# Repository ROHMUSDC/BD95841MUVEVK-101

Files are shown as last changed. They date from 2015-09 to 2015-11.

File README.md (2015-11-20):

# BD95841MUVEVK-101 Design Resource Repository
* Hardware Design Files and Documentation for the ROHM BD95841MUVEVK-101 EVK

----
### Description: 
* BD95841MUV is a 1ch synchronous buck converter that can generate output voltages between 0.8V to 5.5V at an input voltage range of 7.5V to 15V. 
* Built-in N-MOSFET power transistors help to achieve small solution footprint and high efficiency
* Incorporates ROHM's H3Reg(TM) technology, a Rohm proprietary constant ON TIME control mode which facilitates ultra-high transient response against changes in load without external compensation components. 
* Includes fixed soft start function, power good function, and short circuit/over voltage protection with timer latch functions

----
### Repository Contents
* Application Note Folder: Contains Draft Version of EVK Application Note
* Design Files: Contains Board, Gerber, Schematic, and BOM information for this EVK Board
* Measurement Reports Folder: Contains measurement testing information completed for these EVK Boards

----
### Where to Purchase?
* http://www.rohm.com/web/global/distribution/-/dinventory/BD95841MUV-E2/sample/0

----
### DISCLAIMER
This Technical Data is protected under copyright laws.

ROHM hereby grants you a nonexclusive, nontransferable license to use this Technical Data 
as long as you abide by the terms and conditions of this DISCLAIMER. 

However, you are not authorized to sell, loan, rent, lease, redistribute or license this Technical Data, 
in whole or in part, or in modified form, to anyone.

You may modify this Technical Data to suit your specific applications, 
but the rights to derivative works and said modifications shall belong to ROHM. 

You may make copies of this Technical Data as necessary for internal use only within your company.

In any case, the latest datasheet is considered the final design guideline and represents 
the only actual performance specifications.

ROHM shall not be responsible for ensuring proper application on all computer systems.
This Technical Data is provided AS IS. ROHM makes no guarantees, either implicitly or explicitly, 
regarding its usability, functionality, accuracy, merchantability, or fitness for a specific purpose.

In addition, you shall take full responsibility for the use of any information acquired from this Technical Data. 

ROHM does not assume warranty of any kind arising from the use of this Technical Data. ACCORDINGLY, 
IN NO EVENT SHALL ROHM BE RESPONSIBLE, WHETHER THROUGH CONTRACT OR TORT LIABILITY, 
FOR ANY DAMAGES (INCLUDING BUT NOT LIMITED TO LOST PROFITS OR OTHER INCIDENTAL, CONSEQUENTAL, 
OR PUNITIVE DAMAGES) ARISING OUT OF OR IN CONNECTION WITH THE USE OR APPLICATION OF THIS Technical Data.

Furthermore, this Technical Data is subject to change without notice.

Unless otherwise expressly provided herein, ROHM does not convey any license under patent rights 
or any other intellectual property rights (including those of third parties).

ROHM is not obligated to provide maintenance or support for the Technical Data.

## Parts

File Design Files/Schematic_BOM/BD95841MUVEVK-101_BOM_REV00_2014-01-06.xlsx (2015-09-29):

ROHM - TITLE & REVISION HISTORY Revised: Monday, January 06, 2014
xxxx Revision: 00
Bill Of Materials January 6,2014 11:04:57 | Page1
Item | Quantity | Reference | Part | PCB Footprint | DESCRIPTION | MANUFACTURER1 | MANUFACTURER1_PART# | DISTR1 | DISTR1_PART# | DNP
______________________________________________
1 | 1 | CR1 | SML-310MTT86 | LED_0603 | LED 570NM GREEN WTR CLR 0603 SMD | Rohm | SML-310MTT86 | DIGIKEY | 511-1299-1-ND
2 | 2 | C1,C2 | 10uF | C1206 | CAP CER 10UF 25V 20% X5R 1206 | Murata | GRM31CR61E106MA12L | DIGIKEY | 490-5423-1-ND
3 | 1 | C3 | 10000pF | C0603 | CAP CER 10000PF 50V 10% X7R 0603 | Murata | GRM188R71H103KA01D | DIGIKEY | 490-1512-2-ND
4 | 2 | C4,C5 | 22uF | C1206 | CAP CER 22UF 16V 10% X5R 1206 | Murata | GRM31CR61C226KE15K | DIGIKEY | 490-6512-1-ND
5 | 1 | C6 | 0.022uF | C0603 | CAP CER 0.022UF 50V 10% X7R 0603 | Murata | GRM188R71H223KA01D | DIGIKEY | 490-1517-2-ND
6 | 1 | C7 |  | C1206 |  |  |  |  |  | DNP( Do not place )
7 | 1 | C8 |  | C0805 |  |  |  |  |  | DNP( Do not place )
8 | 1 | C9 | 0.1uF | C0603 | CAP CER 0.1UF 25V 10% X7R 0603 | Murata | GRM188R71E104KA01D | DIGIKEY | 490-1524-2-ND
9 | 1 | D1 | SMAJ12A | DO-214AC | TVS DIODE 12VWM 19.9VC SMA | Littelfuse Inc | SMAJ12A | DIGIKEY | SMAJ12ALFTR-ND
10 | 2 | D2,D3 | RB085B-30TL | CPD | DIODE SCHOTTKY 30V 10A CPD | Rohm | RB085B-30TL | DIGIKEY | RB085B-30TLCT-ND | DNP( Do not place )
11 | 1 | J1 | 87224-3 | HDR_THVT_1X3_100 | CONN HEADER VERT .100 3POS 15AU | TE Connectivity Div | 87224-3 | DIGIKEY | A26545-ND
12 | 1 | L1 | 3.3uH | SMT_7P1X6P5 | INDUCTOR 3.3UH 6.8A 20% SMD | TDK Corporation | SPM6530T-3R3M | DIGIKEY | 445-4119-2-ND
13 | 1 | Q1 | SST2222AT116 | SOT23_BEC | TRANSISTOR NPN 40V 0.6A SOT-23 | Rohm | SST2222AT116 | DIGIKEY | SST2222AT116TR-ND
14 | 1 | R2 | 1.5K | R0603 | RES 1.5K OHM 1/10W 1% 0603 SMD | Rohm | RHM1.5KBJTR-ND | DIGIKEY | TRR03EZPF1501
15 | 1 | R3 | 13K | R0603 | RES 13K OHM 1/10W 1% 0603 SMD | Rohm | MCR03ERTF1302 | DIGIKEY | RHM13KCFTR-ND
16 | 1 | R4 | 4.7K | R0603 | RES 4.7K OHM 1/10W 1% 0603 SMD | Rohm | MCR03ERTF4701 | DIFIKEY | RHM4.70KCFTR-ND
17 | 1 | R5 | 100K | R0603 | RES 100K OHM 1/10W 5% 0603 SMD | Rohm | MCR03ERTJ104 | DIGIKEY | RHM100KCGTR-ND
18 | 1 | R6 | 1K | R0603 | RES 1K OHM 1/10W 5% 0603 SMD | Rohm | MCR03ERTJ102 | DIGIKEY | RHM1.0KCGTR-ND
19 | 1 | R7 | 30 | R0603 | RES 30 OHM 1/10W 5% 0603 SMD | Rohm | ESR03EZPJ300 | DIGIKEY | RHM30DTR-ND
20 | 3 | TP1,TP2,TP5 | TP_63Mil_TH | TP_TH | TEST POINT PC MULTI PURPOSE RED | Keystone Electronics | 5010 | DIGIKEY | 5010K-ND
21 | 2 | TP3,TP4 | TP_63Mil_TH | TP_TH | TEST POINT PC MULTI PURPOSE BLK | Keystone Electronics | 5011 | DIGIKEY | 5011K-ND
22 | 1 | U1 | BD95841MUV | VQFN016V3030 | 7.5V to 15V, 4A 1ch Synchronous Buck Converter | ROHM | BD95841MUV
23 | 1 | ZX1 | 0 | SM_180x060 | 1806 footprint solder-short during assembly
24 | 1 |  |  |  | Shunt jumper for header J1 (item #11), CONN SHUNT 2POS GOLD W/HANDLE | TE Connectivity | 881545-1 | DIGIKEY | 881545-1-ND

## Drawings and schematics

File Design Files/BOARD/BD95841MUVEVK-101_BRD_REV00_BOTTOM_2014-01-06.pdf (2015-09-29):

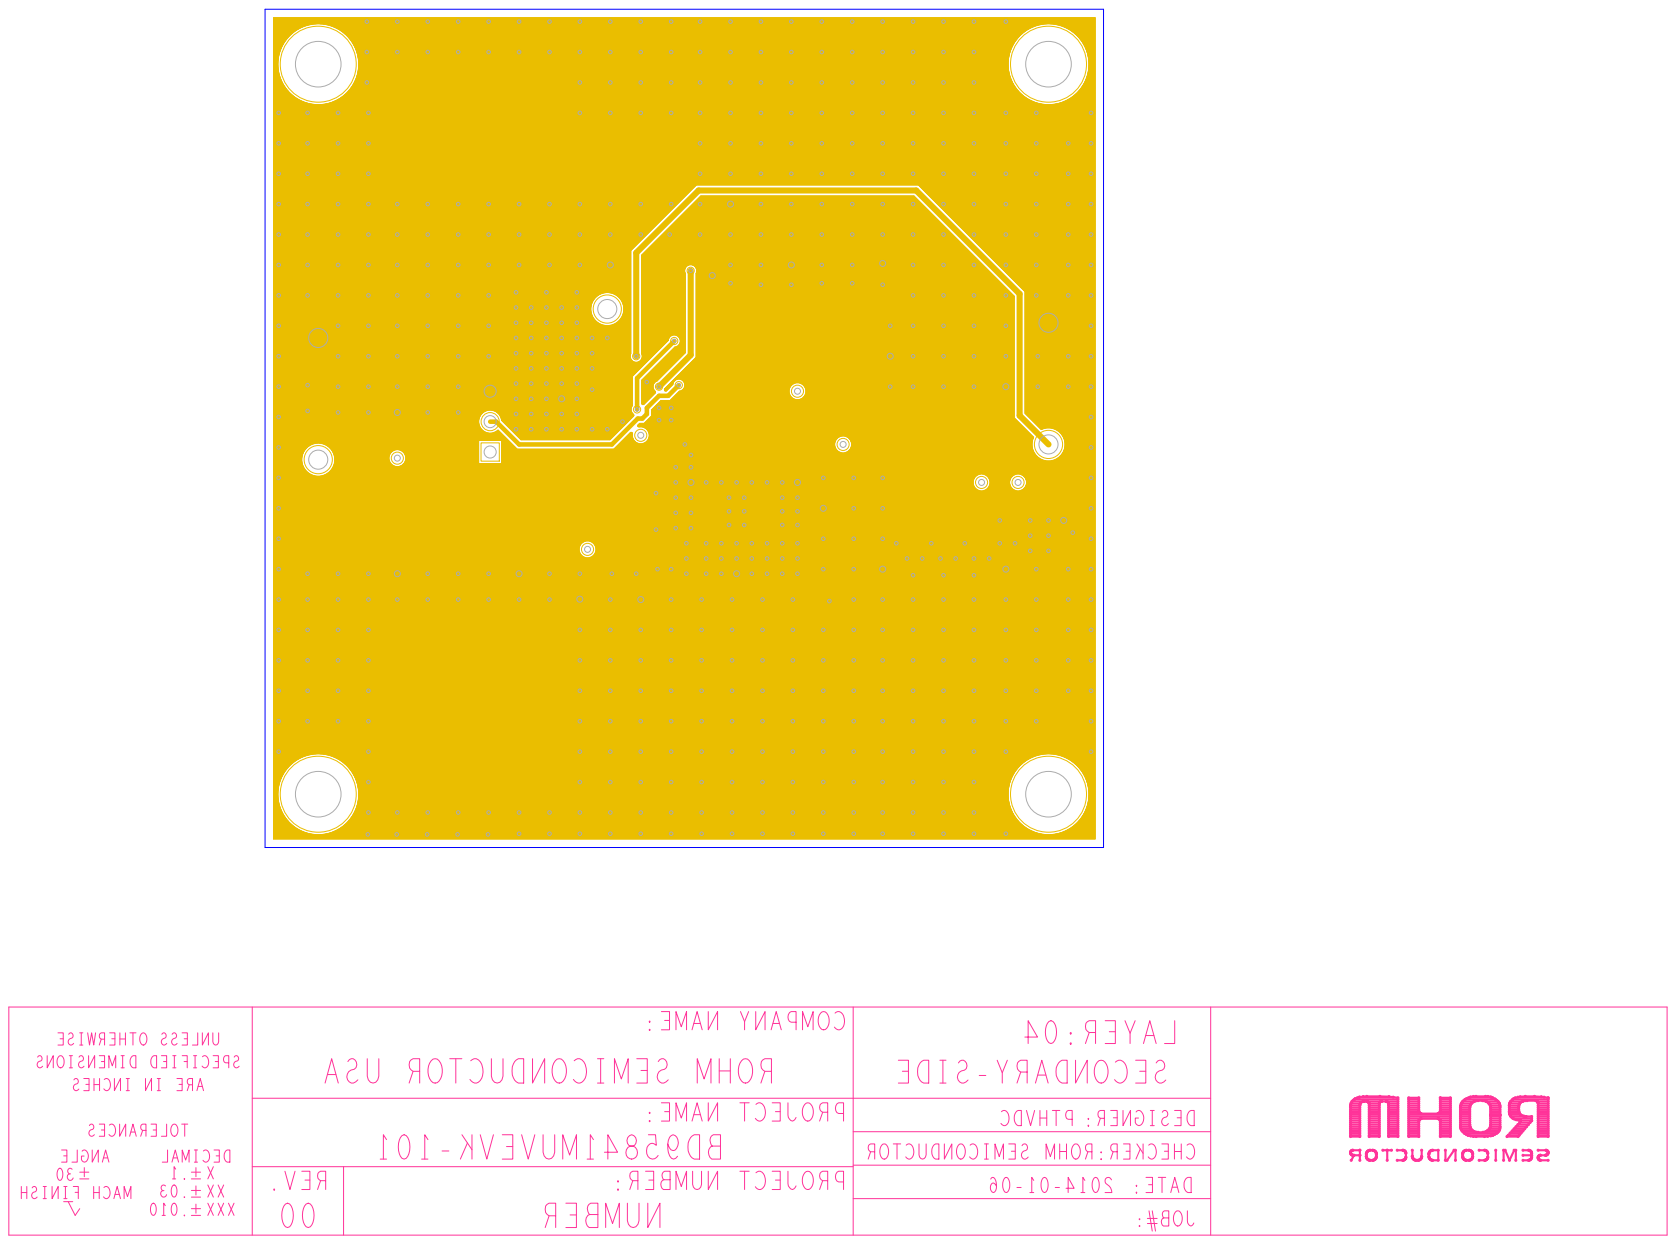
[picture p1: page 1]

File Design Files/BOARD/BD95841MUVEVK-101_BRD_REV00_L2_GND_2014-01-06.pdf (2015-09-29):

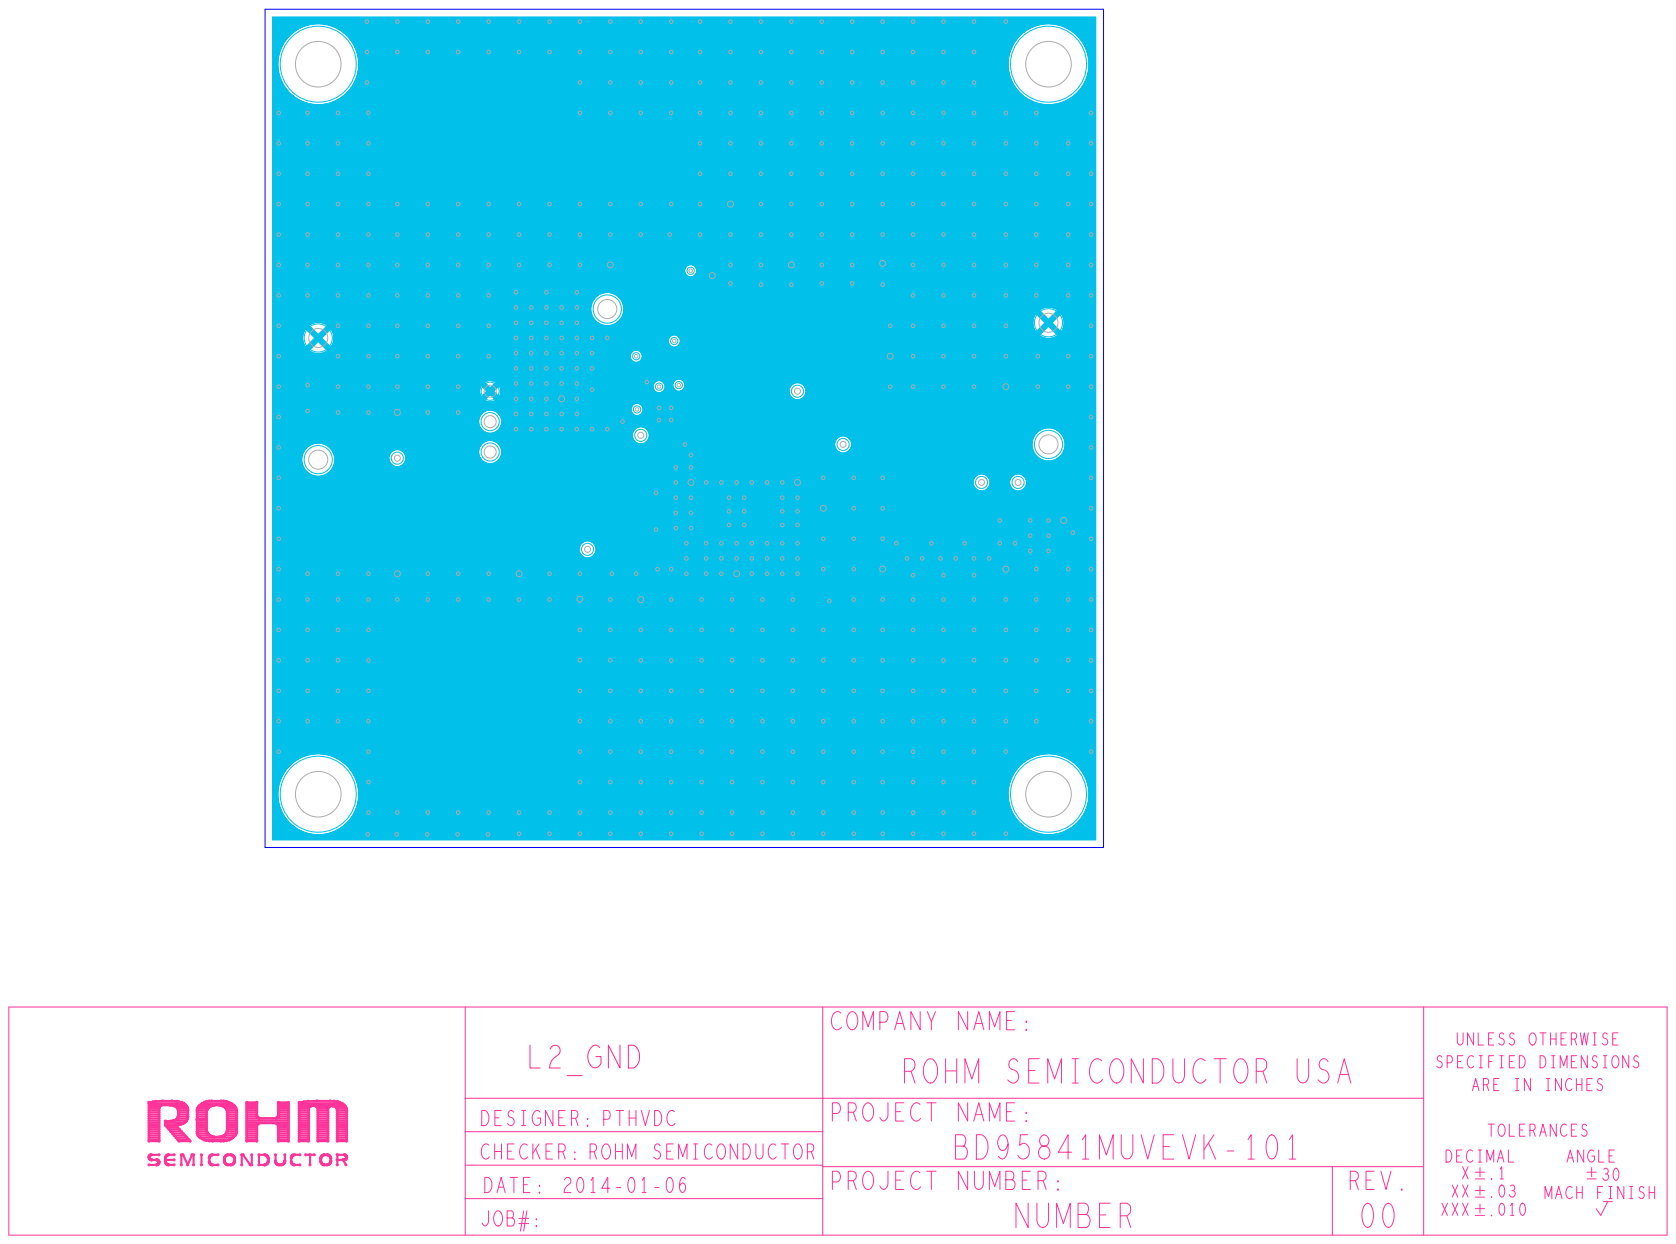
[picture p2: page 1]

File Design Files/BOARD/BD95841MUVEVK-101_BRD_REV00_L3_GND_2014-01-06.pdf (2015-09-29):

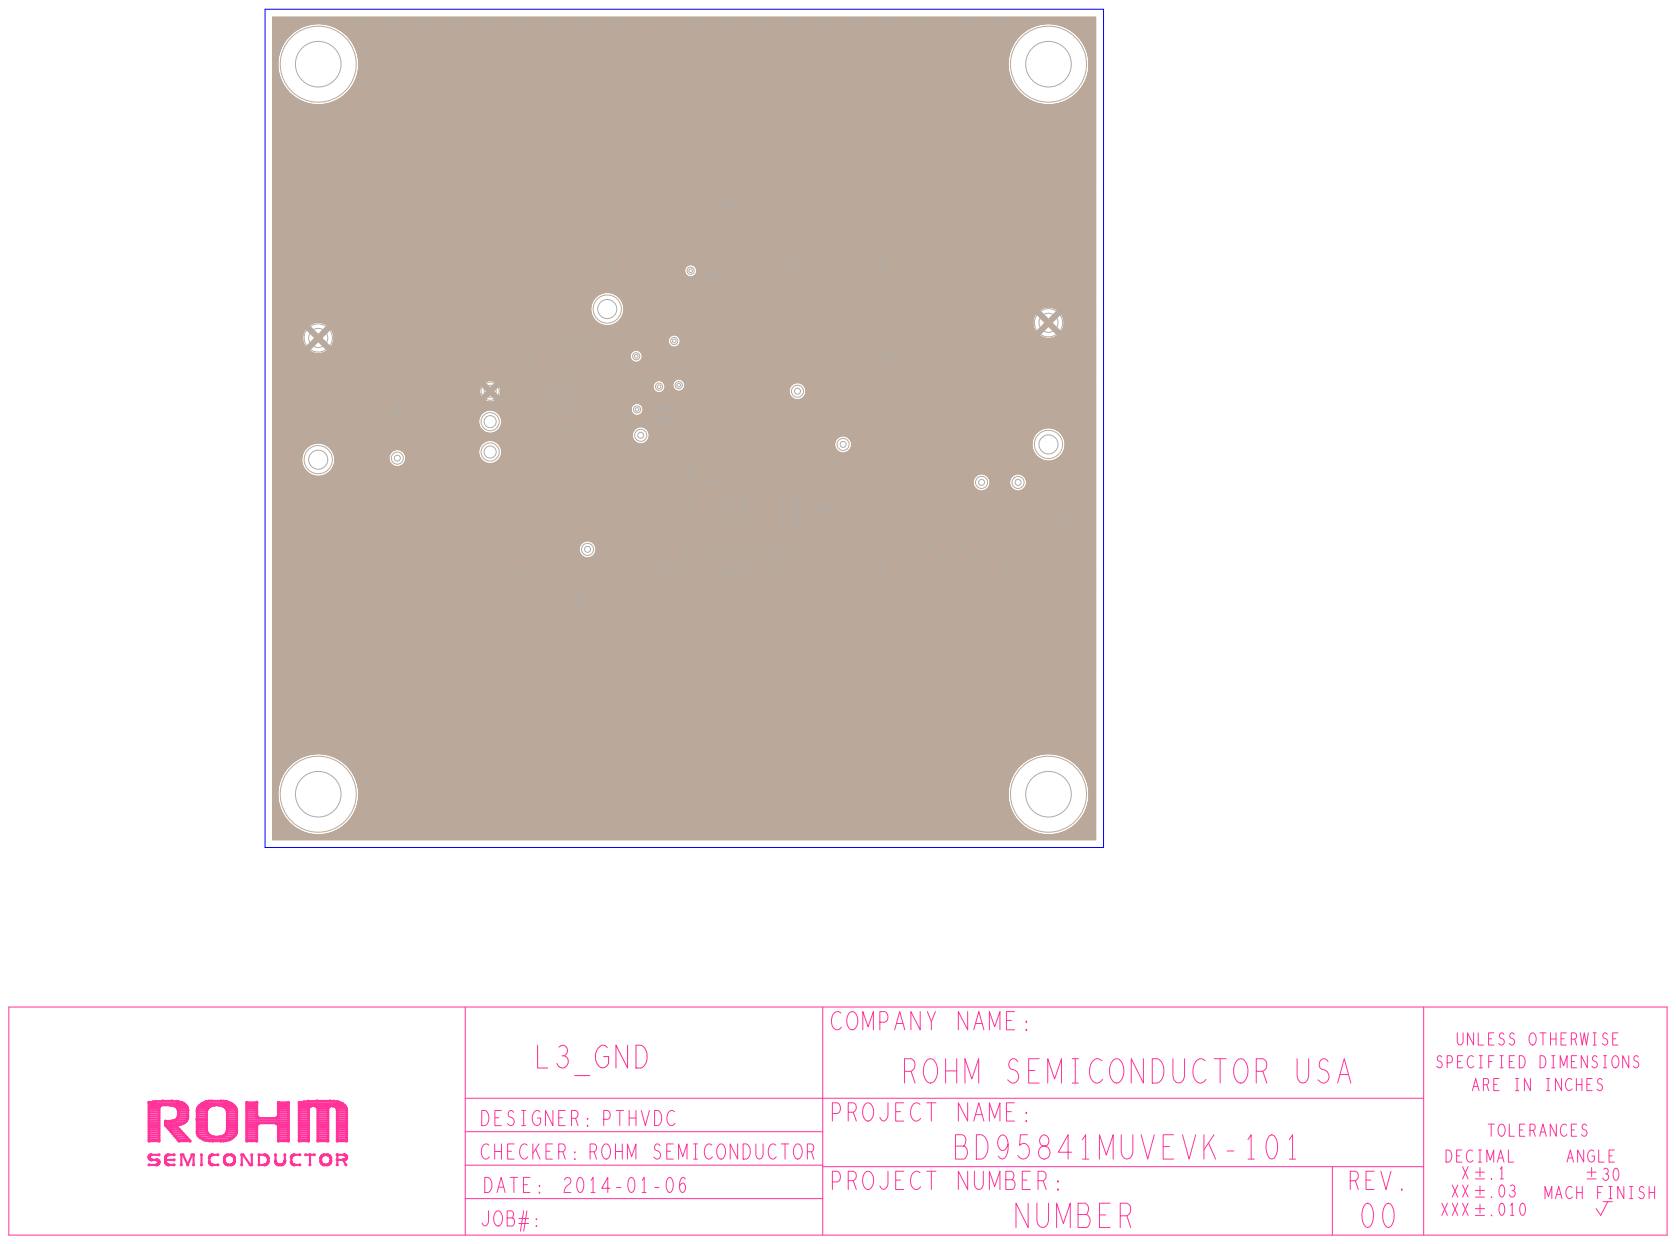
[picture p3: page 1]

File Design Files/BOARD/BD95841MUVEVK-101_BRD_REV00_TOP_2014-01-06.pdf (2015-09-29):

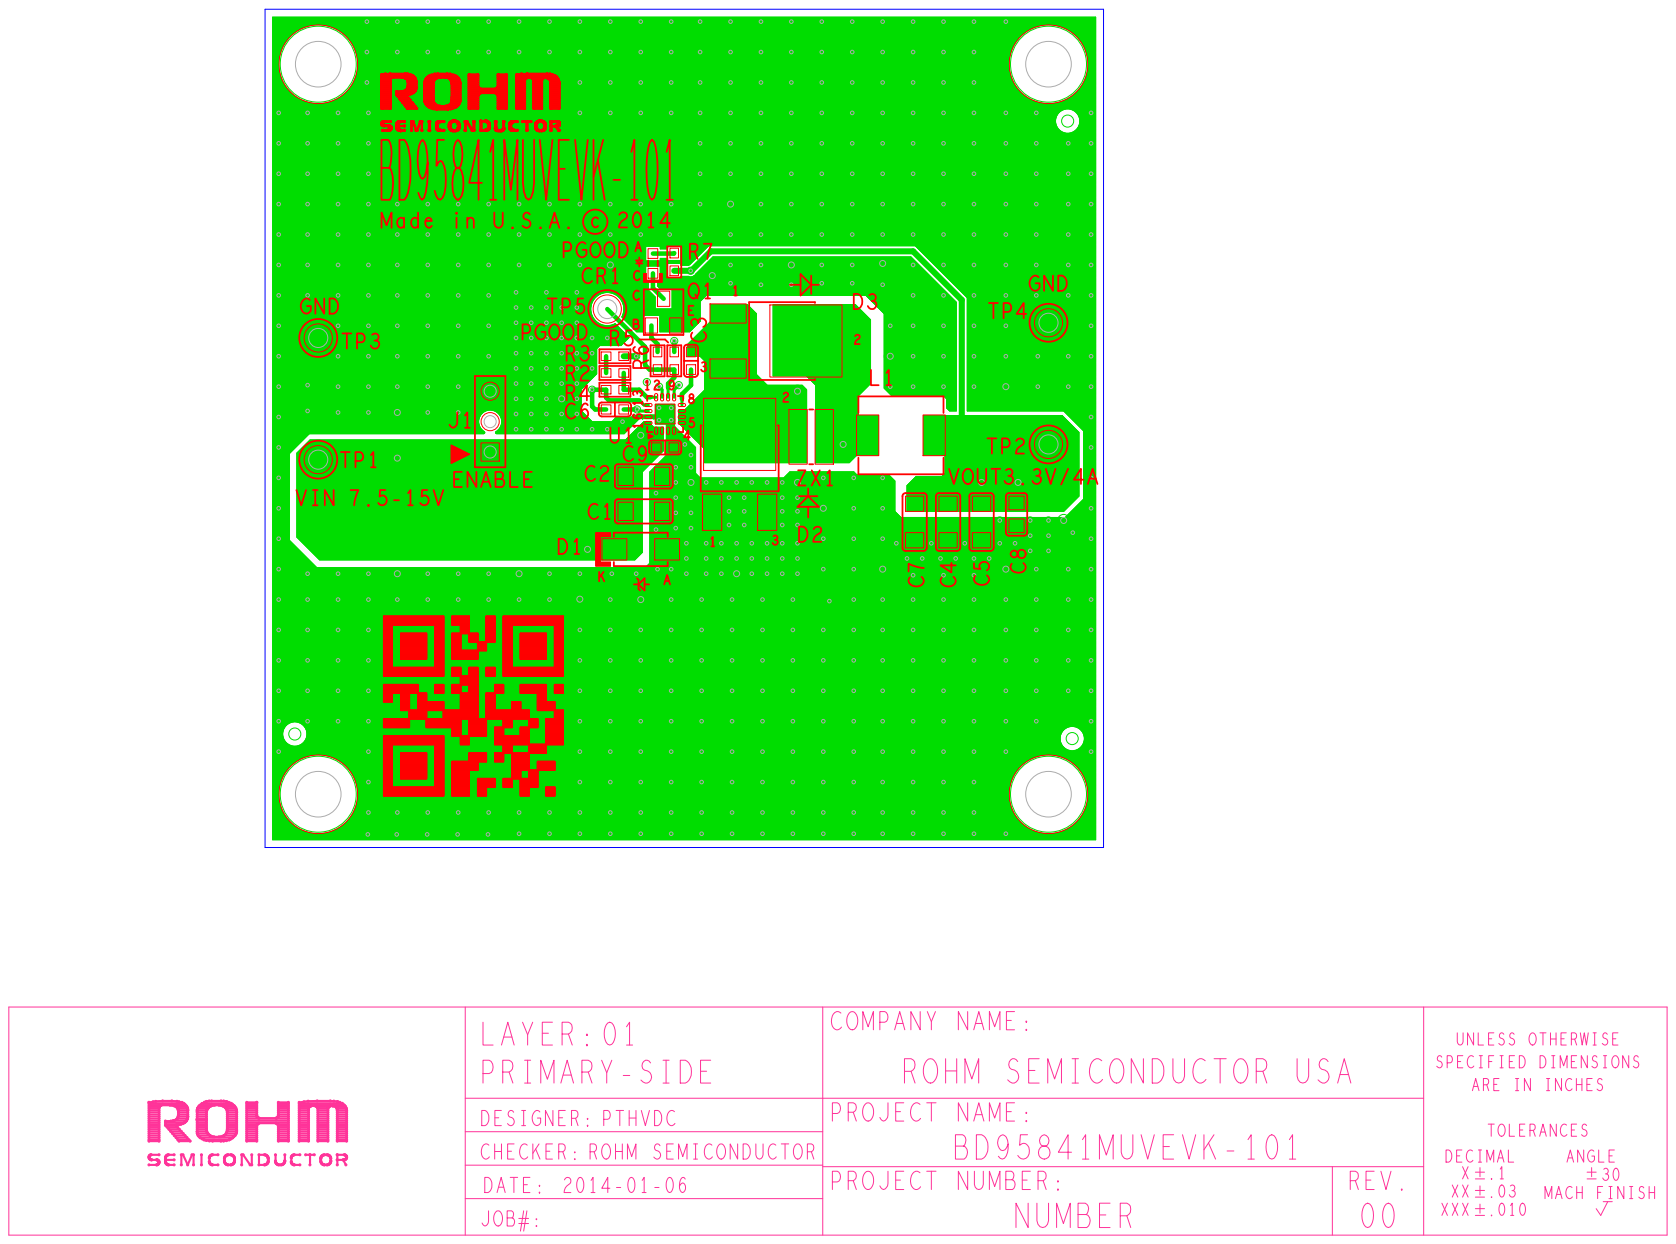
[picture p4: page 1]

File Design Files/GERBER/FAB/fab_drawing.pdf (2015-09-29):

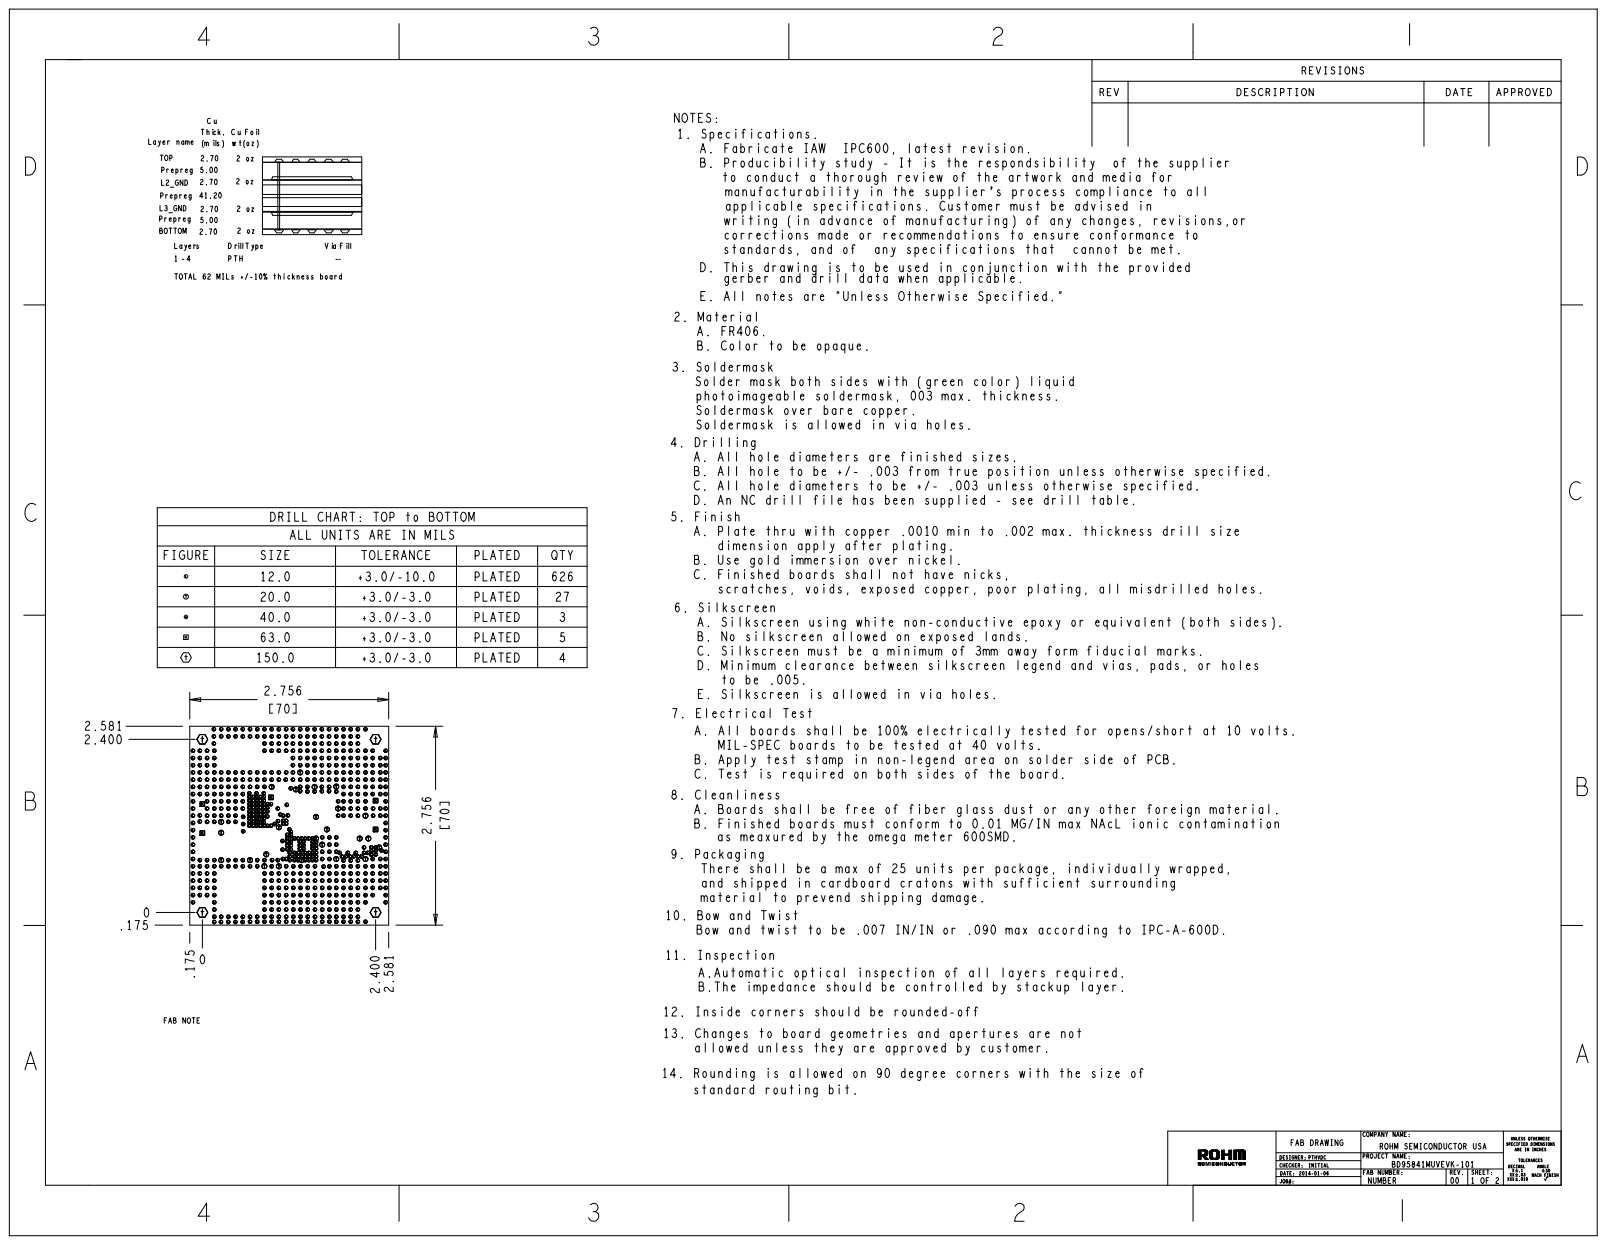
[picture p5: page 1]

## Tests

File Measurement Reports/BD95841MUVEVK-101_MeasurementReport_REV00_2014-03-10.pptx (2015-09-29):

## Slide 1

PTH Solutions Confidential

BD95841MUVEVK-101 Measurement Report
March 10th, 2014
Hosted by: Xuan Dang

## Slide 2

Equipment list

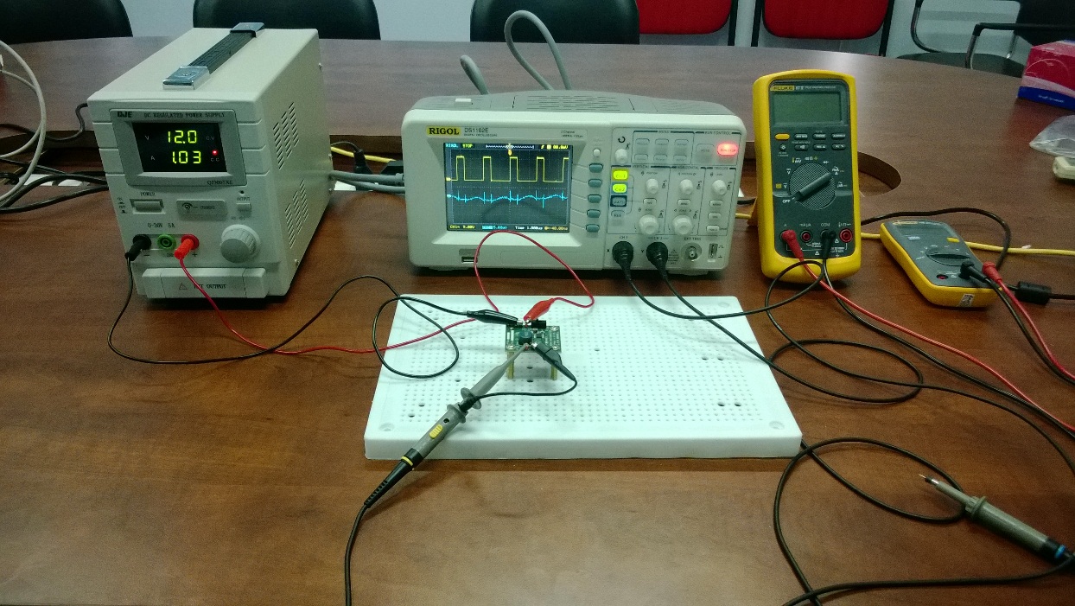
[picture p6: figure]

- Regulated DC Power Supply
  - QJE QJ3005XE (0-30V/5A)
- Multimeter:
  - Fluke 87V True RMS
  - Fluke 106
- Oscilloscope
  - Rigol DS1102E
- Electronic Load
  - B&K BK8500
- Current probe
  - RP1001C

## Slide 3

1. Functional Test

- Testing procedure
  1. Connect DC Supply to: [+]VIN(TP1) and [-]GND(TP3) when EN is off. Set output of DC Supply in range from 7.5V to 15V and turn it on.
  2. Connect Electronic Load to: [+]VOUT(TP2) and [-]GND(TP4). Power on Electronic Load, set input of Electronic Load to 4A and turn on load.
  3. Move J1 header to turn EN on.
- Result:
VIN = 7.5V ~ 15V
IOUT = 4A
VOUT = 3.265V ~ 3.317V. Test passed.

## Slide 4

2. Hot Plugging Test

- Test condition
  - VIN = 15V
  - IOUT = 4A
  - With original diode D1: SMAJ12A
- Result:
- IIN MAX= 86.4A
- VIN peak transient voltage is 17.6V > VIN Maximum Rating (15.2V)

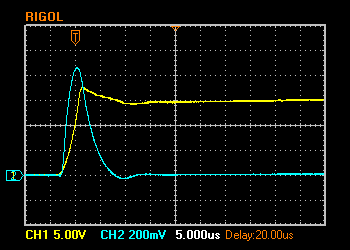
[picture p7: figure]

VIN 5V/Div. (DC)

IIN 20A/Div. (AC)

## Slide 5

3. Circuit Quiescent Current Measurement

- Test condition
  - VIN = 0-15V
  - With SMAJ12A and LED
  - Room temperature 25oC

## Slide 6

4. Efficiency Measurements

- Test condition
  - VIN = 12V
  - VOUT = 3.3V
  - With SMAJ12A and LED
  - Room temperature 25oC

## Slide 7

5. Load Response Measurements

Load response characteristic
(VIN=12V, VOUT=3.3V, IOUT=0 → 4A)

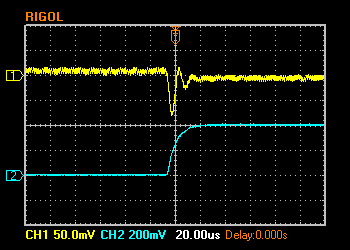
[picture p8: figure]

VOUT 50mV/Div. (AC)

IOUT 2A/Div. (DC)

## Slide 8

5. Load Response Measurements (cont.)

Load response characteristic
(VIN=12V, VOUT=3.3V, IOUT=4A → 0)

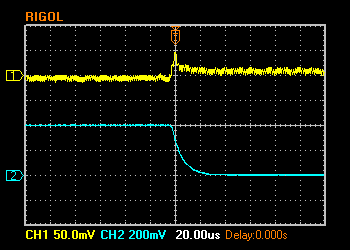
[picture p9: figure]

VOUT 50mV/Div. (AC)

IOUT 2A/Div. (DC)

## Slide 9

6. Ripple Response Measurements

VOUT Ripple voltage
(VIN=12V, VOUT=3.3V, IOUT=4A)

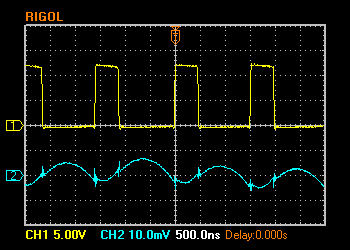
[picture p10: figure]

VSW 5V/Div. (DC)

VOUT 10mV/Div. (AC)

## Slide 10

6. Ripple Response Measurements (cont.)

VOUT Ripple voltage
(VIN=12V, VOUT=3.3V, IOUT=0A)

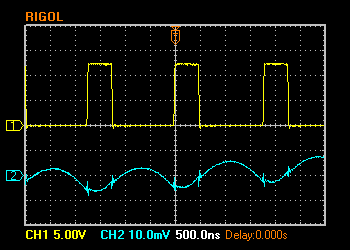
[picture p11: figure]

VSW 5V/Div. (DC)

VOUT 10mV/Div. (AC)

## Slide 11

7. Input Voltage Ripple Measurements

VIN Ripple voltage
(VIN=12V, VOUT=3.3V, CIN=10uF (x2)+ 0.1uF, IOUT=0A)

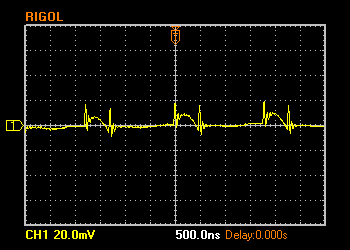
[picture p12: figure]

VIN 20mV/Div. (AC)

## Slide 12

7. Input Voltage Ripple Measurements (cont.)

VIN Ripple voltage
(VIN=12V, VOUT=3.3V, CIN=10uF (x2)+ 0.1uF, IOUT=4A)

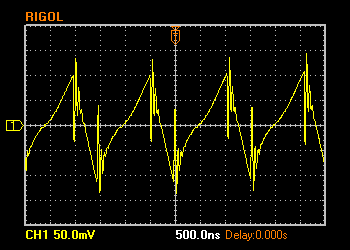
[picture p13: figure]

VIN 50mV/Div. (AC)

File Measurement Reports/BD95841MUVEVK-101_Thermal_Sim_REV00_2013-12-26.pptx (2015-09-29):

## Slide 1

PI and Thermal Simulation Study for BD95841MUV Board
December 26th, 2013
Hosted by: Xuan Dang

PTH Solutions Confidential

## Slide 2

Agenda
  I. Introduction
  II. DC Drop Analysis
  III. Current Density Analysis
  IV. Thermal Analysis
  V. Conclusion

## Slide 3

Introduction

1. This work considers power simulation and thermal simulation on BD95841MUV boards.
  - Based on board file BD95841MUVEVK-101_EVAL_BRD_REV01_20131226_1800.brd
2. Hyperlynx v8.2.1 and Hyperlynx Thermal v9.1 (MentorGraphic) software is used for simulation
3. PI simulation considers:
  a. DC Drop analysis
    - Determine what the max drop for power rail
  b. Current Density analysis
    - Determine the hot spot of current density on PCB
4. Thermal simulation considers:
    - PCB temperature profile including consideration for conductive, radiative, and convective heat transfer

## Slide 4

BD95841MUV Board

- Based on the board file : BD95841MUVEVK-101_EVAL_BRD_REV01_20131226_1800.brd

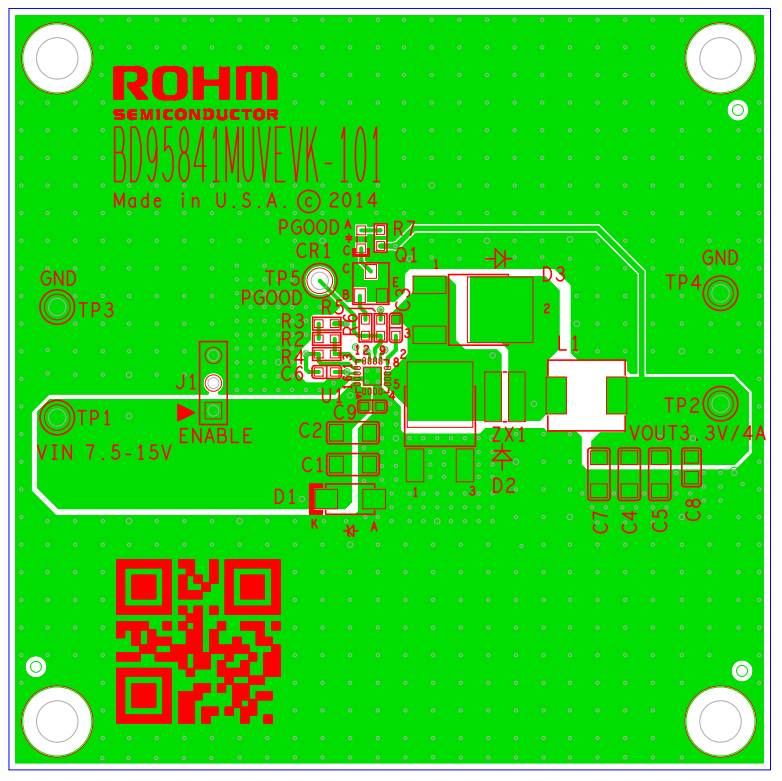
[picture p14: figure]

Vin 5V/div (DC)

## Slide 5

BD95841MUV Schematic

Based on the schematic file : BD95841MUV_EVAL_SCH_REV01_20131226_1800.pdf

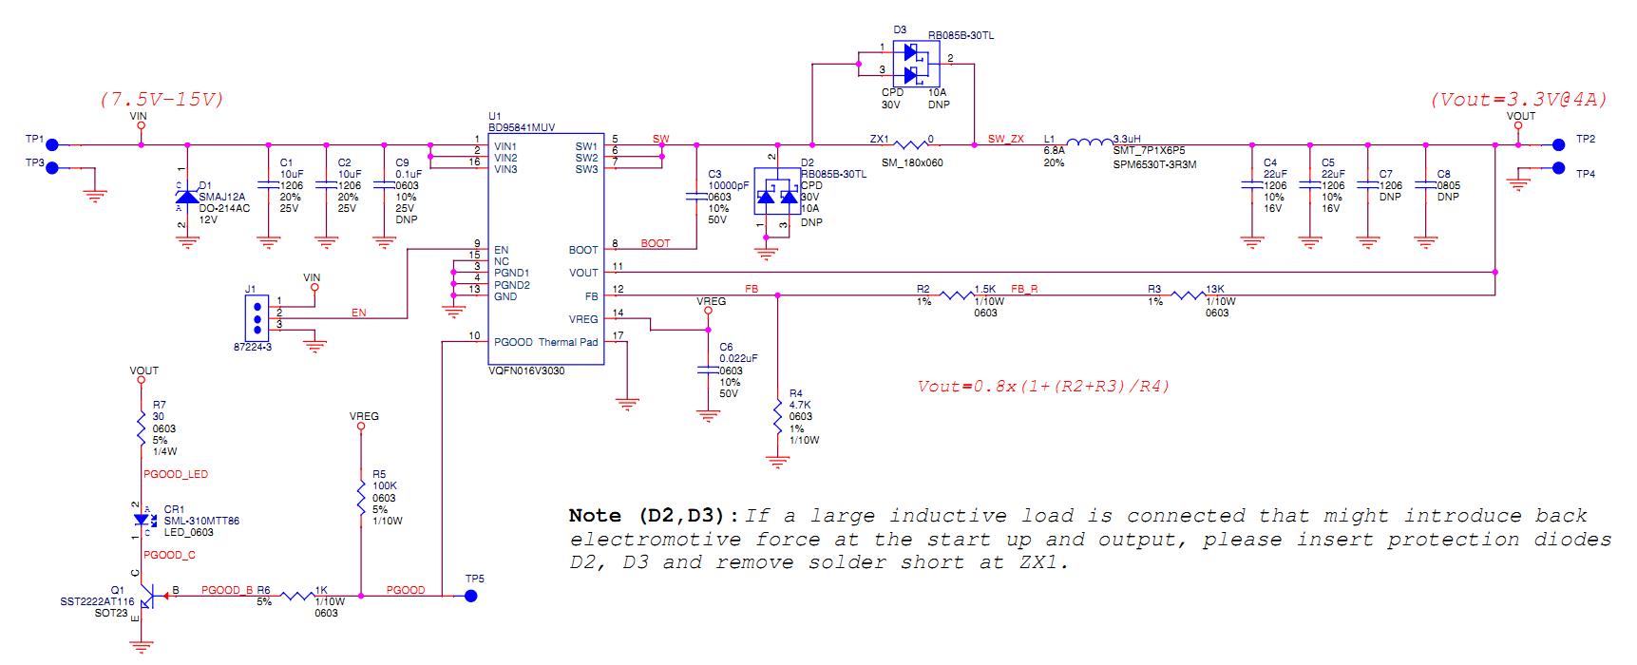
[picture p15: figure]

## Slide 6

BD95841MUV Board power consumption

Device/rail | Source/VRM refdes | Source PCB netname | Sink/load PCB refdes | Load PCB net name | Nominal Voltage(V) | Voltage tolerance (%) | Max current (A) | Power input (W) | Power consumption (W) | Note
Power input via TP1/TP3 connectors (VIN 7.5-15V) | TP1 | VIN | U1 | VIN | 7.50 | | 2.5 | 18.75 | | Max input current = (Pout + PONH + PONL + PL)/VIN = 2.05A with Vin =7.5V (worst condition). So we choose max input current =2.5A to simulate power/thermal
Power dissipation on BD95841MUV internal FETs | TP1 | VIN | U1 | VIN | | | 4.00 | | 1.7216 | RONH=0.13 Ohm; RONL=0.09 Ohm
Power dissipation on inductor L1 | ZX1 | SW | L1 | SW_ZX | | | 4.00 | | 0.4752 | RL = 0.0297 Ohm
Power consumption at load via connector TP2/TP4 (VOUT 3.3V) | L1 | VOUT | TP2 | VOUT | 3.3 | 2 | 4.00 | | 13.2
| | | | | | | Total | 18.75 | 15.3968

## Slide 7

Current Density analysis for VIN 7.5V@2.5A

Source TP1


Max Current Density 20.7 mA/mil² < 40mA/mil² (This rule limit 10 Celsius degree of temperature rise above ambient) → Copper planes for VIN is OK

Load U1

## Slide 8

DC Drop analysis for VIN 7.5V@2.5A

Source TP1


Max DC Drop 2.7mV < 150mV (2% tolerance of 7.5V) → Copper planes for VIN is OK

Load U1

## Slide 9

Current Density analysis for SW@4A


Source U1

Solder-shorted ZX1

Load L1

Max Current Density 25.6mA/mil²<40mA/mil² (This rule limit 10 Celsius degree of temperature rise above ambient) → Copper plane for SW is OK

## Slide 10

DC Drop analysis for SW@4A


Source U1

Solder-shorted ZX1

Load L1

Max DC Drop 0.4 mV < 70mV (2% tolerance of assumption voltage 3.5V) → Copper planes for SW is OK

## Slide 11

Current Density analysis for VOUT 3.3V@4A


Max Current Density 36.8 mA/mil² < 40mA/mil² (This rule limit 10 Celsius degree of temperature rise above ambient) → Copper planes for VOUT is OK

Load TP2

Source L1

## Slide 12

DC Drop analysis for VOUT 3.3V@4A

Source L1


Max DC Drop 1.4 mV < 66mV (2% tolerance of 3.3V) → Copper planes for VOUT is OK

Load TP2

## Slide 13

Thermal Analysis

a. Environment conditions
  a. Air Temperature : 25 ⁰C , 35 ⁰C and 45 ⁰C
  b. Air Pressure: 1 atm
  c. Gravity: 1
  d. Humidity ratio: 0.5%
  e. No incoming air flow (Natural convection)
  f. Emissivity of board: 1
  g. Board location : single board
  h. System: closed

VOUT 20mV/div (AC)

SW 5V/div

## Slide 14

Thermal Analysis (Con’t)

b. Component properties

| BD96841MUV | SPM6530T-3R3M | RB085B-30TL (Diode D3) | SML-310MTT86 | SST2222AT116
Number of pins | 17 | 2 | 3 | 2 | 3
Pin length | 0.024” | 0.134” | 0.063” | 0.032” | 0.05”
Pin width | 0.010” | 0.073” | 0.019” | 0.032” | 0.04”
Pin thickness | 0.0086614” | 0.006” | 0.02” | 0.01” | 0.005”
Pin thermal conductivity | 223.031Btu/hrftF | 223.031Btu/hrftF | 223.031Btu/hrftF | 223.031Btu/hrftF | 223.031Btu/hrftF
Max. power dissipation | 1.7216 W (at Vin=7.5V) 1.616 W (at Vin=12V) | 0.4752 W | 1.92W | 0.044W | 0.012 W

VOUT 20mV/div (AC)

SW 5V/div

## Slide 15

Thermal Analysis (Con’t)

Air temperature 25⁰C, power dissipation of BD95841MUV is 1.7216 W (at VIN=7.5V), exclude power dissipation of DNP diode D3 RB085B-30TL


U1: BD95841MUV
- Max. power dissipation: 1.7216 W @VIN=7.5V
- Component temperature = 57.9 ⁰C

L1: SPM6530T-3R3M
- Max. power dissipation: 0.4752 W
- Component temperature = 38.6 ⁰C

D3:RB085B-30TL
- Component temperature = 37.8 ⁰C

U1

D3

L1

The highest temperature on board is about 41.1 ⁰C
The highest temperature on component is on BD95841MUV ( about 57.9 ⁰C)

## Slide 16

Thermal Analysis (Con’t)

Air temperature 35⁰C, power dissipation of BD95841MUV is 1.7216 W (at VIN=7.5V), exclude power dissipation of DNP diode D3 RB085B-30TL


The highest temperature on board is about 47.6 ⁰C
The highest temperature on component is on BD95841MUV ( about 64.5 ⁰C)

U1: BD95841MUV
- Max. power dissipation: 1.7216 W @VIN=7.5V
- Component temperature = 64.5 ⁰C

L1: SPM6530T-3R3M
- Max. power dissipation: 0.4752 W
- Component temperature = 45.2 ⁰C

D3:RB085B-30TL
- Component temperature = 44.3 ⁰C

U1

D3

L1

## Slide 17

Thermal Analysis (Con’t)

Air temperature 45⁰C, power dissipation of BD95841MUV is 1.7216 W (at VIN=7.5V), exclude power dissipation of DNP diode D3 RB085B-30TL


The highest temperature on board is about 54.3 ⁰C
The highest temperature on component is on BD95841MUV ( about 71.1 ⁰C)

U1: BD95841MUV
- Max. power dissipation: 1.7216 W @VIN=7.5V
- Component temperature = 71.1 ⁰C

L1: SPM6530T-3R3M
- Max. power dissipation: 0.4752 W
- Component temperature = 51.8 ⁰C

D3:RB085B-30TL
- Component temperature = 51 ⁰C

U1

D3

L1

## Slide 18

Thermal Analysis (Con’t)

Air temperature 25⁰C, power dissipation of BD95841MUV is 1.7216 W (at VIN=7.5V), include power dissipation of DNP diode D3 RB085B-30TL


The highest temperature on board is about 63.7 ⁰C
The highest temperature on component is on BD95841MUV ( about 80.6 ⁰C)

U1: BD95841MUV
- Max. power dissipation: 1.7216 W @VIN=7.5V
- Component temperature = 80.6 ⁰C

L1: SPM6530T-3R3M
- Max. power dissipation: 0.4752 W
- Component temperature = 61.6 ⁰C

D3:RB085B-30TL
- Max. power dissipation: 1.92 W
- Component temperature = 64.5 ⁰C

U1

D3

L1

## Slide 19

Thermal Analysis (Con’t)

Air temperature 35⁰C, power dissipation of BD95841MUV is 1.7216 W (at VIN=7.5V), include power dissipation of DNP diode D3 RB085B-30TL


The highest temperature on board is about 69.9 ⁰C
The highest temperature on component is on BD95841MUV ( about 86.9 ⁰C)

U1: BD95841MUV
- Max. power dissipation: 1.7216 W @VIN=7.5V
- Component temperature = 86.9 ⁰C

L1: SPM6530T-3R3M
- Max. power dissipation: 0.4752 W
- Component temperature = 67.8 ⁰C

D3:RB085B-30TL
- Max. power dissipation: 1.92 W
- Component temperature = 70.7 ⁰C

U1

D3

L1

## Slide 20

Thermal Analysis (Con’t)

Air temperature 45⁰C, power dissipation of BD95841MUV is 1.7216 W (at VIN=7.5V), include power dissipation of DNP diode D3 RB085B-30TL


The highest temperature on board is about 76.3 ⁰C
The highest temperature on component is on BD95841MUV ( about 93.3 ⁰C)

U1: BD95841MUV
- Max. power dissipation: 1.7216 W @VIN=7.5V
- Component temperature = 93.3 ⁰C

L1: SPM6530T-3R3M
- Max. power dissipation: 0.4752 W
- Component temperature = 74.2 ⁰C

D3:RB085B-30TL
- Max. power dissipation: 1.92 W
- Component temperature = 77.1 ⁰C

U1

D3

L1

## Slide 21

Thermal Analysis (Con’t)

Air temperature 25⁰C, power dissipation of BD95841MUV is 1.616 W (at VIN=12V), exclude power dissipation of DNP diode D3 RB085B-30TL


The highest temperature on board is about 39.8⁰C
The highest temperature on component is on BD95841MUV ( about 55.6 ⁰C)

U1: BD95841MUV
- Max. power dissipation: 1.616 W @VIN=12V
- Component temperature = 55.6 ⁰C

L1: SPM6530T-3R3M
- Max. power dissipation: 0.4752 W
- Component temperature = 37.6 ⁰C

D3:RB085B-30TL
- Component temperature = 36.7 ⁰C

U1

D3

L1

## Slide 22

Thermal Analysis (Con’t)

Air temperature 35⁰C, power dissipation of BD95841MUV is 1.616 W (at VIN=12V), exclude power dissipation of DNP diode D3 RB085B-30TL


The highest temperature on board is about 46.3 ⁰C
The highest temperature on component is on BD95841MUV ( about 62.1 ⁰C)

U1: BD95841MUV
- Max. power dissipation: 1.616 W @VIN=12V
- Component temperature = 62.1 ⁰C

L1: SPM6530T-3R3M
- Max. power dissipation: 0.4752 W
- Component temperature = 44.2 ⁰C

D3:RB085B-30TL
- Component temperature = 43.2 ⁰C

U1

D3

L1

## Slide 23

Thermal Analysis (Con’t)

Air temperature 45⁰C, power dissipation of BD95841MUV is 1.616 W (at VIN=12V), exclude power dissipation of DNP diode D3 RB085B-30TL


The highest temperature on board is about 53.1 ⁰C
The highest temperature on component is on BD95841MUV ( about 68.9 ⁰C)

U1: BD95841MUV
- Max. power dissipation: 1.616 W @VIN=12V
- Component temperature = 68.9 ⁰C

L1: SPM6530T-3R3M
- Max. power dissipation: 0.4752 W
- Component temperature = 51 ⁰C

D3:RB085B-30TL
- Component temperature = 50.1 ⁰C

U1

D3

L1

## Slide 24

Thermal Analysis (Con’t)

Air temperature 25⁰C, power dissipation of BD95841MUV is 1.616 W (at VIN=12V), include power dissipation of DNP diode D3 RB085B-30TL


The highest temperature on board is about 62.4 ⁰C
The highest temperature on component is on BD95841MUV ( about 78.3 ⁰C)

U1: BD95841MUV
- Max. power dissipation: 1.616 W @VIN=12V
- Component temperature = 78.3 ⁰C

L1: SPM6530T-3R3M
- Max. power dissipation: 0.4752 W
- Component temperature = 60.6 ⁰C

D3:RB085B-30TL
- Max. power dissipation: 1.92 W
- Component temperature = 63.4 ⁰C

U1

D3

L1

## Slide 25

Thermal Analysis (Con’t)

Air temperature 35⁰C, power dissipation of BD95841MUV is 1.616 W (at VIN=12V), include power dissipation of DNP diode D3 RB085B-30TL


The highest temperature on board is about 68.8 ⁰C
The highest temperature on component is on BD95841MUV ( about 84.7 ⁰C)

U1: BD95841MUV
- Max. power dissipation: 1.616 W @VIN=12V
- Component temperature = 84.7 ⁰C

L1: SPM6530T-3R3M
- Max. power dissipation: 0.4752 W
- Component temperature = 67 ⁰C

D3:RB085B-30TL
- Max. power dissipation: 1.92 W
- Component temperature = 69.8 ⁰C

U1

D3

L1

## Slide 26

Thermal Analysis (Con’t)

Air temperature 45⁰C, power dissipation of BD95841MUV is 1.616 W (at VIN=12V), include power dissipation of DNP diode D3 RB085B-30TL


The highest temperature on board is about 75.2 ⁰C
The highest temperature on component is on BD95841MUV ( about 91.1 ⁰C)

U1: BD95841MUV
- Max. power dissipation: 1.616 W @VIN=12V
- Component temperature = 91.1 ⁰C

L1: SPM6530T-3R3M
- Max. power dissipation: 0.4752 W
- Component temperature = 73.4 ⁰C

D3:RB085B-30TL
- Max. power dissipation: 1.92 W
- Component temperature = 76.2 ⁰C

U1

D3

L1

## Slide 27

Summary

1. The PI simulation shows that the max. amount voltage drop of VIN power is 2.7mV, the max. current density of VIN power is 20.7mA/mil²; the max. amount voltage drop of SW power is 0.4mV, the max. current density of SW power is 25.6mA/mil²; the max. amount voltage drop of VOUT power is 1.4mV, the max. current density of VOUT power is 36.8mA/mil²
2. The highest temperature of BD95841MUV board can be reached temperature as table below:

| VIN=4.5V | | VIN=12V
| D1, D3: not install | D1, D3: install | D1, D3: not install | D1, D3: install
Air temperature: 25⁰C | 57.9 ⁰C | 80.6 ⁰C | 55.6 ⁰C | 78.3 ⁰C
Air temperature: 35⁰C | 64.5 ⁰C | 86.9 ⁰C | 62.1 ⁰C | 84.7 ⁰C
Air temperature: 45⁰C | 71.1 ⁰C | 93.3 ⁰C | 68.9 ⁰C | 91.1 ⁰C
